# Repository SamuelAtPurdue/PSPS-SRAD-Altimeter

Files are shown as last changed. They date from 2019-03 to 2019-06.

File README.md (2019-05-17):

# psps_srad_altimeter
<div>
  <h2>Description</h2>
  <br>
  <p>
    PSPS SRAD Altimeter is the backup flight computer for Purdue Space Program Solids 2018/2019. It records altitude, pressure tempurature, and status information to help diagnose problems with opperation and control the recovery system. The altimeter uses breakout boards from Adafruit and Sparkfun and a custom PCB. 
  </p>
</div>

<div>
  <h2>Hardware</h2>
  <br>
  <p>
    This Project uses a custom PCB which is included as eagle files. Hardware list for assembling the PCB can be found in the documentation. The other hardware required are listed below:
    <ul>
      <li> <a href = "https://www.adafruit.com/product/2651">Adafruit BMP280 Breakout</a></li>
      <li> <a href = "https://www.adafruit.com/product/254">Adafruit micro SD Card Breakout</a></li>
      <li> <a href = "https://www.adafruit.com/product/1897">Adafruit SPI FRAM Breakout</a></li>
      <li> <a href = "https://www.sparkfun.com/products/10255">Sparkfun Lipower Boost Converter</a></li>
      <li> <a href = "https://www.sparkfun.com/products/13777">Sparkfun Battery Babysitter</a></li>
    </ul>
  </p>
</div>

<div>
  <h2>Libraries</h2>
  <p>
    This Projects requires some modifications to Adafruit's BMP280 Libraries and the SD Library to work properly. These modified libraries as well as the other ones used are included. Links to the original Libraries below:
    <ul>
      <li> <a href ="https://github.com/adafruit/Adafruit_BMP280_Library">Adafruit BMP280</a></li>
      <li> <a href = "https://github.com/adafruit/SD">SD</a></li>
      <li> <a href = "https://github.com/adafruit/Adafruit_FRAM_SPI">Adafruit SPI FRAM</a></li>
      <li> <a href = "https://github.com/adafruit/Adafruit_Sensor">Adafruit Sensor</a></li>
      <li> <a href = "https://github.com/sparkfun/SparkFun_BQ27441_Arduino_Library">Battery Babysitter</a></li>
    </ul>
  </p>
</div>

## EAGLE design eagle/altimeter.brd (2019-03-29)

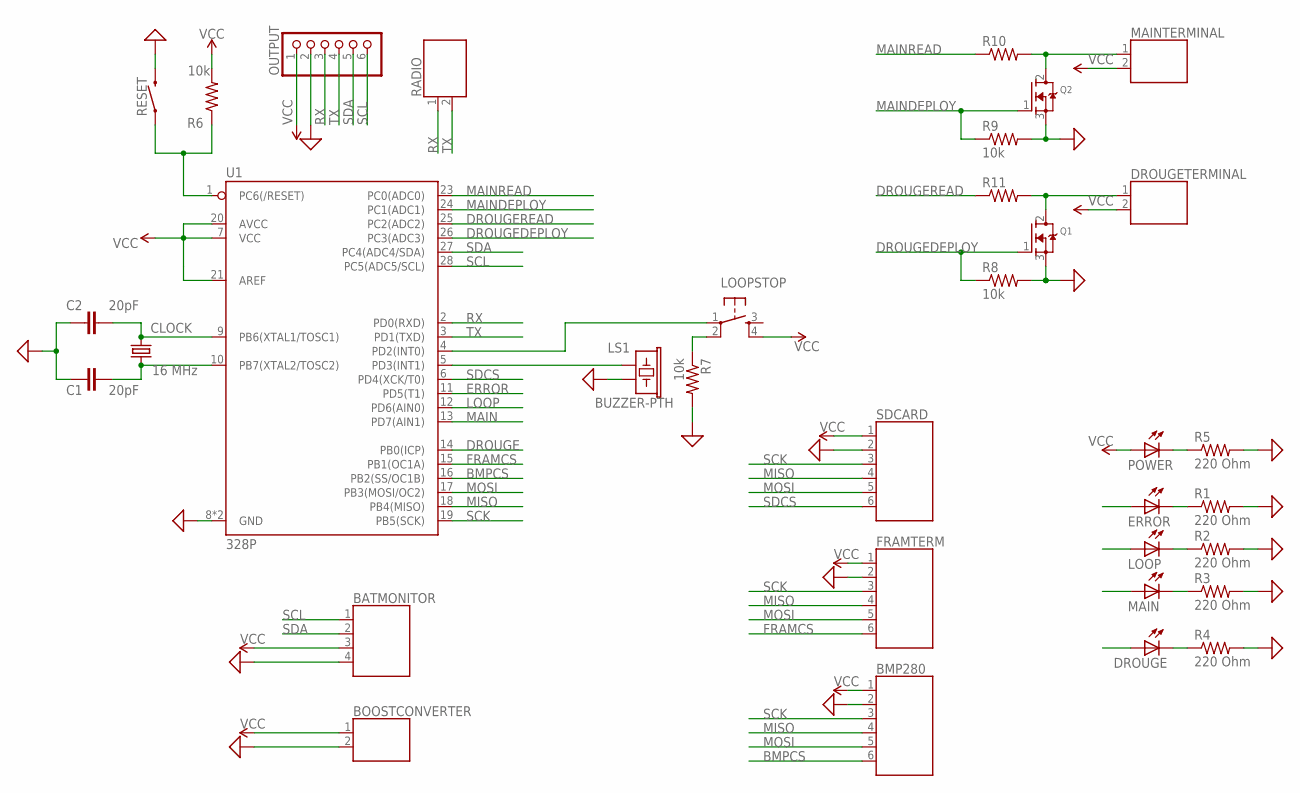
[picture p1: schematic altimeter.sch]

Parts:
BATMONITOR: 691386700004
BMP280: 691386700006
BOOSTCONVERTER: 691386700002
C1, C2: 20pF; CAP-PTH-2.54
CLOCK: 16 MHz; HC49U-V
DROUGE: LED5MM
DROUGETERMINAL: 691386700002
ERROR: LED5MM
FRAMTERM: 691386700006
LOOP: LED5MM
LOOPSTOP: TAC_SWITCHPTH; TACTILE-PTH
LS1: BUZZER-PTH; BUZZER-12MM
MAIN: LED5MM
MAINTERMINAL: 691386700002
OUTPUT: PINHD-1X6; 1X06
POWER: LED5MM
Q1, Q2: MOSFET-NGDS_TO220V; TO220V
R1, R2, R3, R4, R5: 220 Ohm; 0204/7
R6, R7, R8, R9: 10k; 0204/7
R10, R11: R-US_0204/7; 0204/7
RADIO: 691386700002
RESET: MOMENTARY-SWITCH-SPST-PTH-6.0MM; TACTILE_SWITCH_PTH_6.0MM
SDCARD: 691386700006
U1: 328P; DIP28

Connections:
BMPCS: BMP280.6, U1.16 (PB2(SS/OC1B))
DROUGE: DROUGE.A, U1.14 (PB0(ICP))
DROUGEDEPLOY: Q1.1 (G), R8.1, U1.26 (PC3(ADC3))
DROUGEREAD: R11.1, U1.25 (PC2(ADC2))
ERROR: ERROR.A, U1.11 (PD5(T1))
FRAMCS: FRAMTERM.6, U1.15 (PB1(OC1A))
GND: BATMONITOR.4, BMP280.2, BOOSTCONVERTER.2, C1.1, C2.1, FRAMTERM.2, LS1.- (2), OUTPUT.2, Q1.3 (S), Q2.3 (S), R1.2, R2.2, R3.2, R4.2, R5.2, R7.2, R8.2, R9.2, RESET.3 (2), SDCARD.2, U1.8 (GND), U1.22 (GND)
LOOP: LOOP.A, U1.12 (PD6(AIN0))
MAIN: MAIN.A, U1.13 (PD7(AIN1))
MAINDEPLOY: Q2.1 (G), R9.1, U1.24 (PC1(ADC1))
MAINREAD: R10.1, U1.23 (PC0(ADC0))
MISO: BMP280.4, FRAMTERM.4, SDCARD.4, U1.18 (PB4(MISO))
MOSI: BMP280.5, FRAMTERM.5, SDCARD.5, U1.17 (PB3(MOSI/OC2))
unnamed: C1.2, CLOCK.1, U1.10 (PB7(XTAL2/TOSC2))
unnamed: C2.2, CLOCK.2, U1.9 (PB6(XTAL1/TOSC1))
unnamed: POWER.K (C), R5.1
unnamed: LOOPSTOP.2, R7.1
unnamed: LOOPSTOP.1, U1.4 (PD2(INT0))
unnamed: LS1.+ (1), U1.5 (PD3(INT1))
unnamed: DROUGETERMINAL.1, Q1.2 (D), R11.2
unnamed: MAINTERMINAL.1, Q2.2 (D), R10.2
unnamed: ERROR.K (C), R1.1
unnamed: LOOP.K (C), R2.1
unnamed: MAIN.K (C), R3.1
unnamed: DROUGE.K (C), R4.1
unnamed: R6.1, RESET.1, U1.1 (PC6(/RESET))
RX: OUTPUT.3, RADIO.1, U1.2 (PD0(RXD))
SCK: BMP280.3, FRAMTERM.3, SDCARD.3, U1.19 (PB5(SCK))
SCL: BATMONITOR.1, OUTPUT.6, U1.28 (PC5(ADC5/SCL))
SDA: BATMONITOR.2, OUTPUT.5, U1.27 (PC4(ADC4/SDA))
SDCS: SDCARD.6, U1.6 (PD4(XCK/T0))
TX: OUTPUT.4, RADIO.2, U1.3 (PD1(TXD))
VCC: BATMONITOR.3, BMP280.1, BOOSTCONVERTER.1, DROUGETERMINAL.2, FRAMTERM.1, LOOPSTOP.4, MAINTERMINAL.2, OUTPUT.1, POWER.A, R6.2, SDCARD.1, U1.7 (VCC), U1.20 (AVCC), U1.21 (AREF)

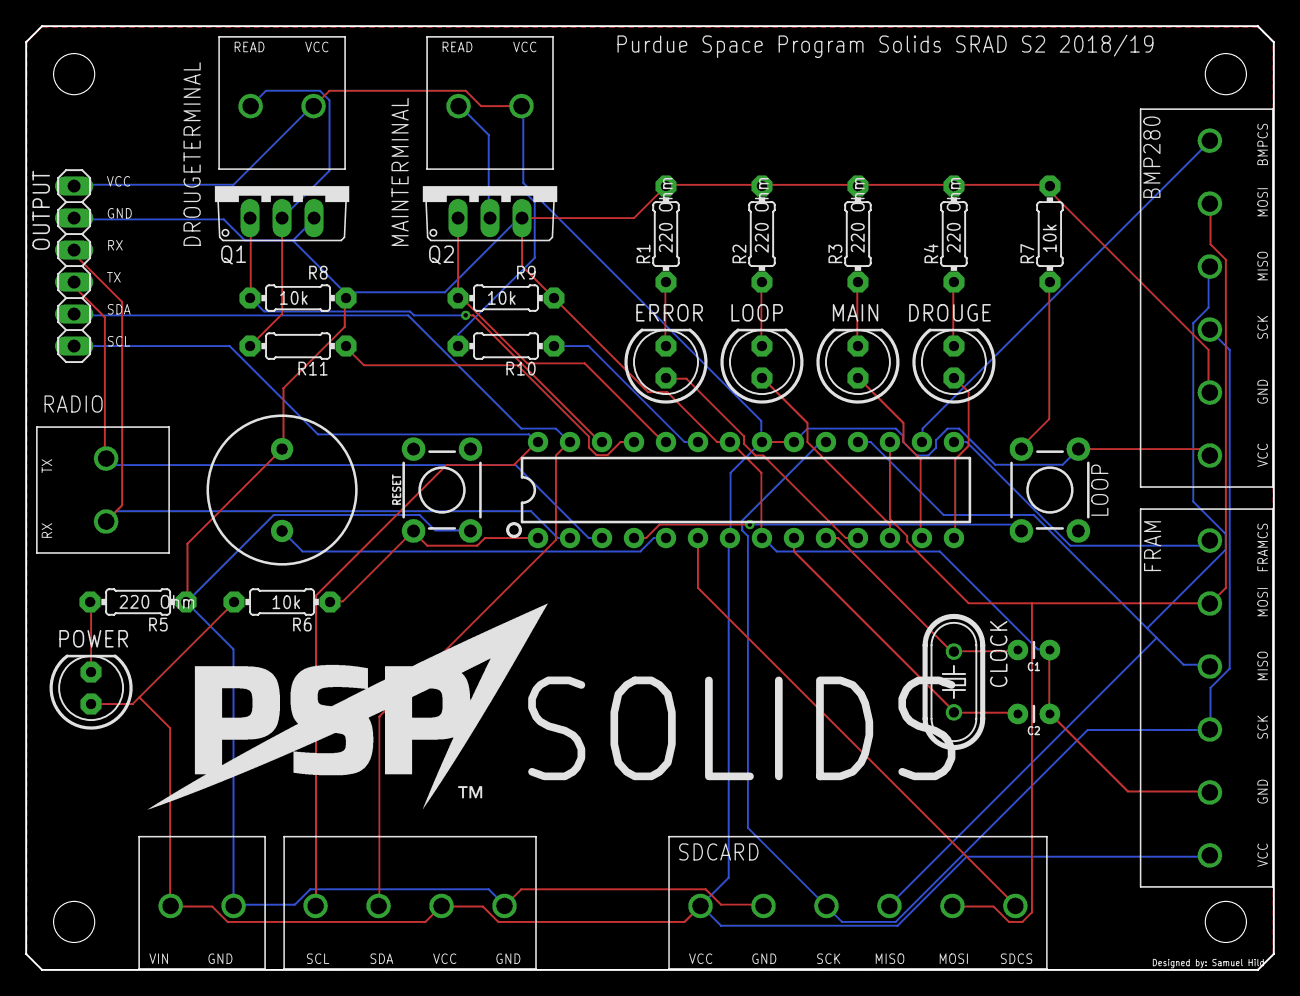
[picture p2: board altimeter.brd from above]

Board: 2 copper layers, 99.1 x 74.9 mm, 34 parts (0 on the bottom side), 33 nets.

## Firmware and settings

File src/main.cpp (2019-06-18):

/*
 * src:		        main.cpp
 * description:	  main file for execution
 * Author:	      Samuel Hild
 */
#include <Utility.hpp>
#include <SparkFunBQ27441.h>
#include <EEPROM.h>

#include <Altimeter.hpp>
#include <Storage.hpp>

bool healthCheck1();
bool healthCheck2();

void setupGpio();
bool setupBattery();
bool setupPrimaryStorage();
bool setupSecondaryStorage();
bool setupRadio();

void collectRaw(collectedData *);

void writeData(collectedData *);
void transmitTelemetry(collectedData *);
void writeDataEEPROM(collectedData *);
void framWrite(collectedData *);
void writeFloat(float, int = 0, bool = false);

float calculateVelocity(collectedData *, collectedData *);


Altimeter * altimeter;
Storage * primaryStorage;
Storage * secondaryStorage;
Runmode current;

collectedData previousData;
collectedData currentData;

uint32_t liftoffTime = 0;
uint32_t framCounter = 0;
float framRate = 0;

extern bool programmingMode;

/*
 * function:	     setup()
 * description:	   simulated setup() function
 * input(s):	     void
 * output(s):	     void
 * author:	       Samuel Hild
 */
void setup()
{
  //Initial Setup
  setupGpio();
  Serial.begin(9600);

  if (!healthCheck1()) 
    fatal (F("health check 1 failed"));

  // setup battery
  while (!setupBattery())
  {
    error (F("failure to start battery"));
    if (digitalRead(LOOP_STOP) == HIGH)
    {
      alert (F("interupt detected"));
      debug (F("programming mode active"));

      blink(LOOP_LED);
      blink(LOOP_LED);

      programmingMode = true;

      delay(1000);
      break;
    }
    delay (STARTUP_DELAY);
  }

  if (programmingMode)
  {
    debug(F("begin EEPROM dump"));

    for (unsigned int i = 0; i < EEPROM.length(); i++)
    {
      Serial.print(F("0x"));
      Serial.print(EEPROM.read(i), HEX);
      Serial.print(F(" "));
    }
    Serial.println();
  }

  // Setup Altimeter
  altimeter = buildAltimeter();

  setupPrimaryStorage();

  setupSecondaryStorage();

  digitalWrite(LOOP_LED, HIGH);

  // make initial reading
  collectRaw(&previousData);
  collectRaw(&currentData);

  // Set Default Values
  previousData.velocity = 0;
  previousData.acceleration = 0;

  currentData.velocity = 0;
  currentData.acceleration = 0;

  while (currentData.pressure < 0 || currentData.pressure == ERRANT_PRESSUE)
  {
    collectRaw(&currentData);
    transmitTelemetry(&currentData);
    error(F("pressure error"));
    delay(1000);
  }

  delay (500);
  current = Runmode::PREFLIGHT;
}

/*
 * function:	  loop()
 * description: main loop for all inflight actions
 * input(s):	  void
 * output(s):	  void
 * author:	    Samuel Hild
 */
void loop()
{
  digitalWrite(LOOP_LED, HIGH);
  
  debug(F("loop begin"));

  collectRaw(&currentData);
  currentData.velocity = calculateVelocity(&currentData, &previousData);

  writeDataEEPROM(&currentData);
  writeData(&currentData);
  if (programmingMode) framWrite(&currentData);
  
  transmitTelemetry(&currentData);
  
  switch (current)
  {
    case Runmode::PREFLIGHT :
      if ((currentData.altitude >= (altimeter->getInitialAltitude() + LAUNCH_ALTITUDE_THRESHOLD)) || 
        (currentData.velocity >= LAUNCH_VELOCITY_THRESHOLD) || 
        (currentData.acceleration >= LAUNCH_ACCELERATION_THRESHOLD))
        {
          liftoffTime = currentData.timestamp;
          current = Runmode::BURN;
          framRate = BURN_SAMPLE_RATE;  
          break;    // Skips over the delay
        }

      delay (REFRESH_RATE*2);
      break;
    
    case Runmode::BURN :
      if (currentData.acceleration <= 0 || currentData.timestamp > (liftoffTime + BURN_TIME_THRESHOLD))
      {
        current = Runmode::ASCENT;
        framRate = ASCENT_SAMPLE_RATE;
      }

      break;

    case Runmode::ASCENT :
      if (currentData.velocity <= APOGEE_VELOCITY_THRESHOLD)
      {
        current = Runmode::APOGEE;
      }
      break;

    case Runmode::APOGEE :
      if (currentData.velocity <= 0)
      {
        // Deploy DROUGE
        digitalWrite(DROGUE_DEPLOY, HIGH);
        delay(DEPLOY_DELAY);
        digitalWrite(DROGUE_DEPLOY, LOW);

        if (analogRead(DROGUE_READ) > 500) 
        {
          error(F("deploy error detected drogue"));
          digitalWrite(DROGUE_DEPLOY, HIGH);
        }
        
        current = Runmode::DROGUE;
      }
      
      break;

    case Runmode::DROGUE :
      if (currentData.altitude <= (MAIN_ALTITUDE_THRESHOLD + altimeter->getInitialAltitude()))
      {
        digitalWrite(DROGUE_LED, LOW);
        digitalWrite(MAIN_DEPLOY, HIGH);
        delay(DEPLOY_DELAY);
        digitalWrite(MAIN_DEPLOY, LOW);

        if (analogRead(MAIN_READ) > 500)
        {
          error(F("deploy error detected main"));
          digitalWrite(MAIN_DEPLOY, HIGH);
        }

        current = Runmode::MAIN;
      }

      break;

    case Runmode::MAIN :
      if ((currentData.velocity >= ZERO_THRESHOLD) || currentData.altitude <= altimeter->getInitialAltitude())
        current = Runmode::POSTFLIGHT;

      break;

    case Runmode::POSTFLIGHT :

      // Safety Checks
      digitalWrite(DROGUE_DEPLOY, LOW);
      digitalWrite(MAIN_DEPLOY, LOW);

      digitalWrite(DROGUE_LED, (analogRead(DROGUE_READ) < 500) ? HIGH : LOW);
      digitalWrite(MAIN_LED, (analogRead(MAIN_READ) < 500) ? HIGH : LOW);

      // final Reading
      collectRaw(&currentData);
      writeData(&currentData);
      framWrite(&currentData);
      transmitTelemetry(&currentData);

      alert (F("end of flight detected"));
      digitalWrite(LOOP_LED, LOW);

      primaryStorage->close();

      alert (F("operations terminated"));

      blink(LOOP_LED);
      blink(LOOP_LED);

      for (;;);

    default:
      fatal(F("unknown runmode"));
      break;
  }

  if (framRate != 0 && currentData.timestamp >= framCounter)
  {
    framWrite(&currentData);
    framCounter += 1000 / framRate;
  }

  // Interupt Detection
  if (digitalRead(LOOP_STOP) == HIGH)
  {
    alert (F("interupt detected"));
    digitalWrite(LOOP_LED, LOW);

    primaryStorage->close();

    alert (F("operations terminated"));

    blink(LOOP_LED);
    blink(LOOP_LED);

    for (;;);
  }

  dataCopy(&previousData, &currentData);

  delay (REFRESH_RATE);
}

/*
 * function:	  setupGpio()
 * description:	sets up gpio display
 * input(s):	  void
 * output(s):	  void
 * author:	    Samuel Hild
 */
void setupGpio()
{
  pinMode(LOOP_STOP, INPUT);

  pinMode(ERROR_LED, OUTPUT);
  pinMode(LOOP_LED, OUTPUT);
  pinMode(MAIN_LED, OUTPUT);
  pinMode(DROGUE_LED, OUTPUT);

  pinMode(MAIN_DEPLOY, OUTPUT);
  pinMode(DROGUE_DEPLOY, OUTPUT);

  pinMode(SDCS, OUTPUT);
  pinMode(BMPCS, OUTPUT);

  
}

/*
 * function:    healthCheck1()
 * description: Performs an initial health check of the system
 * input(s):    void
 * output(s):   bool success, return true on success
 * author:      Samuel Hild
 */
bool healthCheck1()
{

  debug(F("begin startup"));

  // Check Leds
  for (int i = 0; i < 4; i++)
  {
    blink(ERROR_LED + i);
  }

  float mainRead = analogRead(MAIN_READ);

  if (RADIO_ENABLE)
  {
    debug(F("main read: "));
    Serial.println(mainRead);
  }

  if (mainRead < 500)
  {
    digitalWrite(MAIN_LED, HIGH);
    error(F("main charge discontinuous"));
  }

  float drogueRead = analogRead(DROGUE_READ);

  if (RADIO_ENABLE)
  {
    debug(F("drogue read: "));
    Serial.println(drogueRead);
  }

  if (drogueRead < 500)
  {
    digitalWrite(DROGUE_LED, HIGH);
    error(F("drogue charge discontinuous"));
  }

  debug(F("Health Check 1 complete"));

  return true;
}

bool setupBattery()
{
  if(lipo.begin())
  {
    lipo.setCapacity(BATTERY_CAPACITY);

    debug(F("battery startup successful"));

    if (RADIO_ENABLE)
    {
      debug(F("dump initial battery info"));
      Serial.print(lipo.voltage());
      Serial.println("mV");

      Serial.print(lipo.current(AVG));
      Serial.println("mA");

      Serial.print(lipo.capacity(REMAIN));
      Serial.println("mAh");
    }

    return true;
  }
  return false;
}


bool setupPrimaryStorage()
{
  // Setup Storage
  primaryStorage = buildStorage(1);
  delay (STARTUP_DELAY);

  return primaryStorage->isActive();
}

bool setupSecondaryStorage()
{
  secondaryStorage = buildStorage();
  return secondaryStorage->open();
}

/*
 * function:    collectRaw
 * description: Collects raw data from the sensors
 * input(s):    collectedData * data, the struct to store the data
 * output(s):   void
 * author:      Samuel Hild
 */
void collectRaw(collectedData * data)
{
  debug(F("start collecting data"));

  data->timestamp = millis();
  (data->number)++;

  if (RADIO_ENABLE) Serial.println(data->number);

  data->altitude = altimeter->readAltitude();
  data->pressure = altimeter->readPressure();
  data->tempurature = altimeter->readTemperature();

  data->ram = freeRam();
  data->mainVoltage = analogRead(MAIN_READ);
  data->drogueVoltage = analogRead(DROGUE_READ);

  data->lipoVoltage = (programmingMode) ? 3.6 : lipo.voltage();
  data->lipoCurrent = (programmingMode) ? 0.040 : lipo.current(AVG);
  data->lipoCapacity = (programmingMode) ? 1900 : lipo.capacity(REMAIN);  
}

/*
 * function:    writeData
 * description: writes data to primary storage
 * input(s):    collectedData * data, the datastructure to store
 * output(s):   void
 * author:      Samuel Hild
 */
void writeData(collectedData * data)
{

  debug(F("writing data to sd card"));

  if(primaryStorage->isActive())
  {
    writeFloat(data->timestamp);

    writeFloat(data->altitude, 2);
    writeFloat(data->pressure, 2);
    writeFloat(data->tempurature, 1);
    writeFloat(data->velocity, 2);

    writeFloat(data->ram);
    writeFloat(data->mainVoltage);
    writeFloat(data->drogueVoltage);

    writeFloat(data->lipoCurrent, 2);
    writeFloat(data->lipoVoltage, 2);
    writeFloat(data->lipoCapacity, 2, true);
  }

  debug(F("data writen to sd card"));
}

/*
 * function:    transmitTelemetry
 * description: Transmits data over the radio
 * input(s):    collectedData * data, the data to transmit
 * output(s):   void
 * author:      Samuel Hild
 */
void transmitTelemetry(collectedData * data)
{
  if (RADIO_ENABLE)
    debug(F("DATA PACKET: "));

  Serial.print((uint32_t) data->timestamp);
  Serial.print(",");
  Serial.print((uint32_t) data->pressure);
  Serial.print(",");
  Serial.print((uint8_t) data->tempurature);
  Serial.print(",");
  Serial.print((uint16_t) data->ram);
  Serial.print(",");
  Serial.print((uint8_t) data->lipoVoltage);
  Serial.print(",");
  Serial.print((uint8_t) (data->mainVoltage / 100));
  Serial.print(",");
  Serial.print((uint8_t) (data->drogueVoltage / 100));

  Serial.println();

  if (RADIO_ENABLE)
    Serial.print("\n\n");
  
  
}

/*
 * function:    healthCheck2
 * description: checks the status of the device after setup
 * input(s):    void
 * output(s):   bool success, shows whether the device is operational
 * author:      Samuel Hild
 */
bool healthCheck2()
{


  // Check continuity
  debug(F("verify drogue"));
  digitalWrite(DROGUE_LED, (analogRead(DROGUE_READ) < 500) ? HIGH : LOW);

  debug(F("verify main"));
  digitalWrite(MAIN_LED, (analogRead(MAIN_READ) < 500) ? HIGH : LOW);

  // take test Reading
  collectRaw(&currentData);

  if (RADIO_ENABLE)
  {
    debug(F("dump initial data"));

    Serial.println(currentData.timestamp);
    Serial.println(currentData.number);

    Serial.println(currentData.altitude);
    Serial.println(currentData.pressure);
    Serial.println(currentData.tempurature);

    Serial.println(currentData.ram);
    Serial.println(currentData.mainVoltage);
    Serial.println(currentData.drogueVoltage);

    Serial.println(currentData.lipoVoltage);
    Serial.println(currentData.lipoCurrent);
    Serial.println(currentData.lipoCapacity);
  }  

  if (currentData.pressure < 0 || currentData.pressure == ERRANT_PRESSUE)
    error(F("pressure error"));

  return true;
}

void writeDataEEPROM(collectedData * data)
{
  debug(F("storing in EEPROM"));

  EEPROM.put(0, altimeter->getMaxAltitude());
  EEPROM.put(sizeof(float), * data);

  debug(F("end collecting data"));
}

void framWrite(collectedData * data)
{
  debug(F("Writing to Fram"));

  uint8_t temp = 0x00;
  if(RADIO_ENABLE) Serial.println((uint16_t) data->timestamp);

  for (int i = sizeof(uint32_t) - sizeof(uint8_t); i >= 0; i-=1)
  {
    temp = (uint8_t) (((uint32_t) data->timestamp) >> i*8);
    secondaryStorage->write(temp);

    if (RADIO_ENABLE) Serial.print(temp, HEX);
    temp = 0x00;
  }
  
  if (RADIO_ENABLE) Serial.println();

  secondaryStorage->write((uint8_t) ',');
  if(RADIO_ENABLE) Serial.println((uint32_t) data->pressure);

  for (int i = sizeof(uint32_t) - sizeof(uint8_t); i >= 0; i-=1)
  {
    temp = ((uint32_t) data->pressure) >> i*8;
    secondaryStorage->write(temp);

    if (RADIO_ENABLE) Serial.print(temp, HEX);
    temp = 0x00;
  }

  if (RADIO_ENABLE) Serial.println();

  secondaryStorage->write((uint8_t)',');
  if(RADIO_ENABLE) Serial.println((uint16_t) data->ram);

  for (int i = sizeof(uint16_t) - sizeof(uint8_t); i >= 0; i-=1)
  {
    temp = ((uint16_t) data->ram) >> i*8;
    secondaryStorage->write(temp);

    if (RADIO_ENABLE) Serial.print(temp, HEX);
    temp = 0x00;
  }

  if (RADIO_ENABLE) Serial.println();

  secondaryStorage->write((uint8_t)',');
  secondaryStorage->write((uint8_t) data->lipoVoltage);

  secondaryStorage->write((uint8_t)',');
  secondaryStorage->write((uint8_t) (data->mainVoltage / 100));

  secondaryStorage->write((uint8_t)',');
  secondaryStorage->write((uint8_t) (data->drogueVoltage / 100));
  secondaryStorage->write((uint8_t)'\n');
}

float calculateVelocity(collectedData * previous, collectedData * recent)
{
  float deltaT = (float) (recent->timestamp - previous->timestamp) / 1000.0;
  float deltaH = (float) ((round(recent->altitude)) - (round(previous->altitude)));
  float velocity = deltaH / deltaT;

  debug(F("Calculated Velocity"));
  if (RADIO_ENABLE) Serial.println(velocity);

  return velocity;
}

void writeFloat(float num, int precision, bool end)
{
  char buffer[25];
  char * writeData;

  writeData = dtostrf(num, 1, precision, buffer);
  primaryStorage->write(writeData);
  primaryStorage->write((end) ? "\n" : ",");
}

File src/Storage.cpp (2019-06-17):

/*
 * src:	        Storage.cpp
 * description:	Source file for all storage related functionality
 * author:	    Samuel Hild
 */

#include <Storage.hpp>
#include <SPI.h>
#include <SD.h>
#include <Utility.hpp>
#include <Adafruit_FRAM_SPI.h>

#define FILENAME "data.txt"

bool programmingMode = false;

/*
 * interface:	  SdStorage
 * description: class for SD card storage
 * Author: 	    Samuel Hild
 */
class SdStorage : public Storage
{
private:
  File datafile;
  bool active = false;

protected:
public:
  SdStorage(){}

  bool open() override
  {
    bool success = SD.begin(SDCS);

    if (success)
      datafile = SD.open(FILENAME, FILE_WRITE);

    active = success && datafile;

    return active;
  }

  void write(const char * data) override
  {
    datafile.print(data);
  }

  void write(uint8_t data) override
  {
    datafile.print(data);
  }

  void close() override
  {
    datafile.close();
  }
  bool isActive() override
  {
    return active;
  }
};

/*
 * class:       FramStorage
 * description: class for FRAM Storage
 * author:      Samuel Hild
 */
class FramStorage : public Storage
{
private:
  Adafruit_FRAM_SPI fram = Adafruit_FRAM_SPI(FRAMCS);
  uint32_t previousAddress = 0x00;
  bool active = false;

protected:
public:
  FramStorage() {}

  bool open()
  {
    active = fram.begin();
    debug(F("fram dump:"));
    if (active && programmingMode)
    {
      uint8_t read;
      for (int i = 0; i < FRAM_SIZE; i++)
      {
        read = fram.read8(i);

        if (!((i + 1) % 19))
        {
          Serial.println();
        }
        else
        {
          Serial.print("0x");
        
          if (read < 0x10)
            Serial.print(F("0"));

          Serial.print(read, HEX);
          Serial.print(F(" "));
        }
      }
      if(RADIO_ENABLE) Serial.println();
    }
    return active;
  }
  
  void write(const char * data)
  {

    fram.writeEnable(true);
    for (unsigned int i = 0; i < sizeof(*data) / sizeof(char); i++)
    {
      if (!RADIO_ENABLE)
      {
        debug(F("writing data to FRAM"));
        Serial.println(*data + i);
      }
      previousAddress += sizeof(uint8_t);
      fram.write8(previousAddress, *data+i);
    }
    fram.writeEnable(false);
  }

  void write (uint8_t data)
  {
    fram.writeEnable(true);
    fram.write8(previousAddress, data);
    previousAddress += sizeof(uint8_t);
    fram.writeEnable(false);
  }

  void close()
  {
    /* Not needed */
    Serial.println(F("[??] warn: FramStorage::close() has no implementation"));
  }

  bool isActive()
  {
    return active;
  }
};

/*
 * function:	  buildStorage()
 * description:	Factory function for creating an instance of Storage
 * input(s):	  int, selection, the type of Storage to create
 * output(s):	  Storage, new instance of Storage
 * Author: 	    Samuel Hild
 */
Storage * buildStorage(int selection)
{
  Storage * newStorage;
  if (selection == 1)
  {
      newStorage = new SdStorage();

      if (newStorage->open())
        debug(F("sd startup successful"));
      else
        error(F("failed to start sd storage"));
  }
  else
    newStorage = new FramStorage();
  
  return newStorage;
}

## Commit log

2019-02-28 Added Eagle Files
    [altimeter_new.brd, altimeter_new.sch]
2019-03-29 Created project structure and updated eagle files
    [altimeter.brd, altimeter.sch]

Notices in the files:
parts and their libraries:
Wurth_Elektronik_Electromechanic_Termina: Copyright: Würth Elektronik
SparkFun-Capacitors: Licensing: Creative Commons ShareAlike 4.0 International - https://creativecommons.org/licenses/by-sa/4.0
